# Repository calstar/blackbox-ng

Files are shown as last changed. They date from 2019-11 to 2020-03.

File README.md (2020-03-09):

View this project on [CADLAB.io](https://cadlab.io/project/2320). 

# blackbox-ng
This is the third major revision of STAR's black box project. Previous versions may be found on this git, and even older versions may be found on grabcad.

The major changes in this revision are the switch to kicad, the adjustment of the mounting holes pattern, and the switch to a more reliable linear regulator.

The project is seperated into a main logging board, and several spi daughter boards which can be chained together on an ffc cable and mounted about the vehicle.

## Daughter Boards

At present all daughter boards use jumpers to select the appropriate chipselect lines, but pin mappings are designed to allow us to chain an arbitrary number of devices on a single chain using 74 series shift registers. They also all share a common hole pattern and form factor.

### adxl372

This daughter board has a footprint for the adxl372, as well as a footprint for it's breakout board. The adxl372 is a relatively high bandwidth mems accelerometer that we plan on using to derive vibration data from.

### Debug Board (aka vronsky-daughter)

This board has a .1" header so that it can be used to access the signals of all the pins on its connector. It also has a footprint for a high speed barometric pressure sensor, in order to serve as a backup logging system for the pitot tube project.

### BMP388

This board is currently under development by Zitao and an attachment for STAR's next standard barometric pressure sensor. It is not yet production ready, but will likely be going out in the next board run.

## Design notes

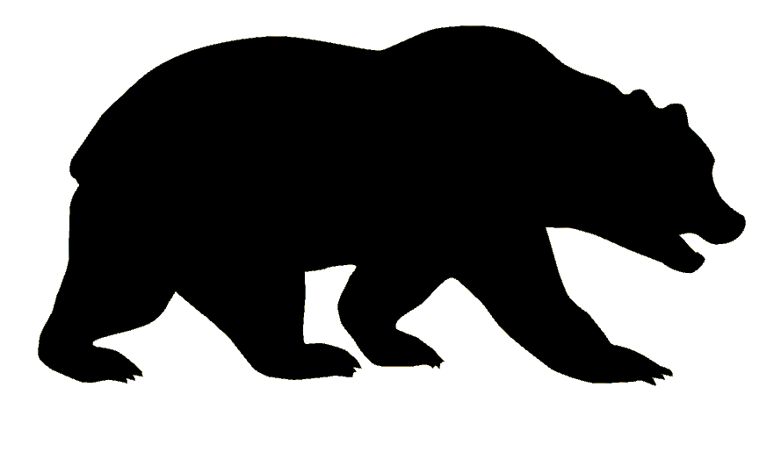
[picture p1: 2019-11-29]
art/bear.png

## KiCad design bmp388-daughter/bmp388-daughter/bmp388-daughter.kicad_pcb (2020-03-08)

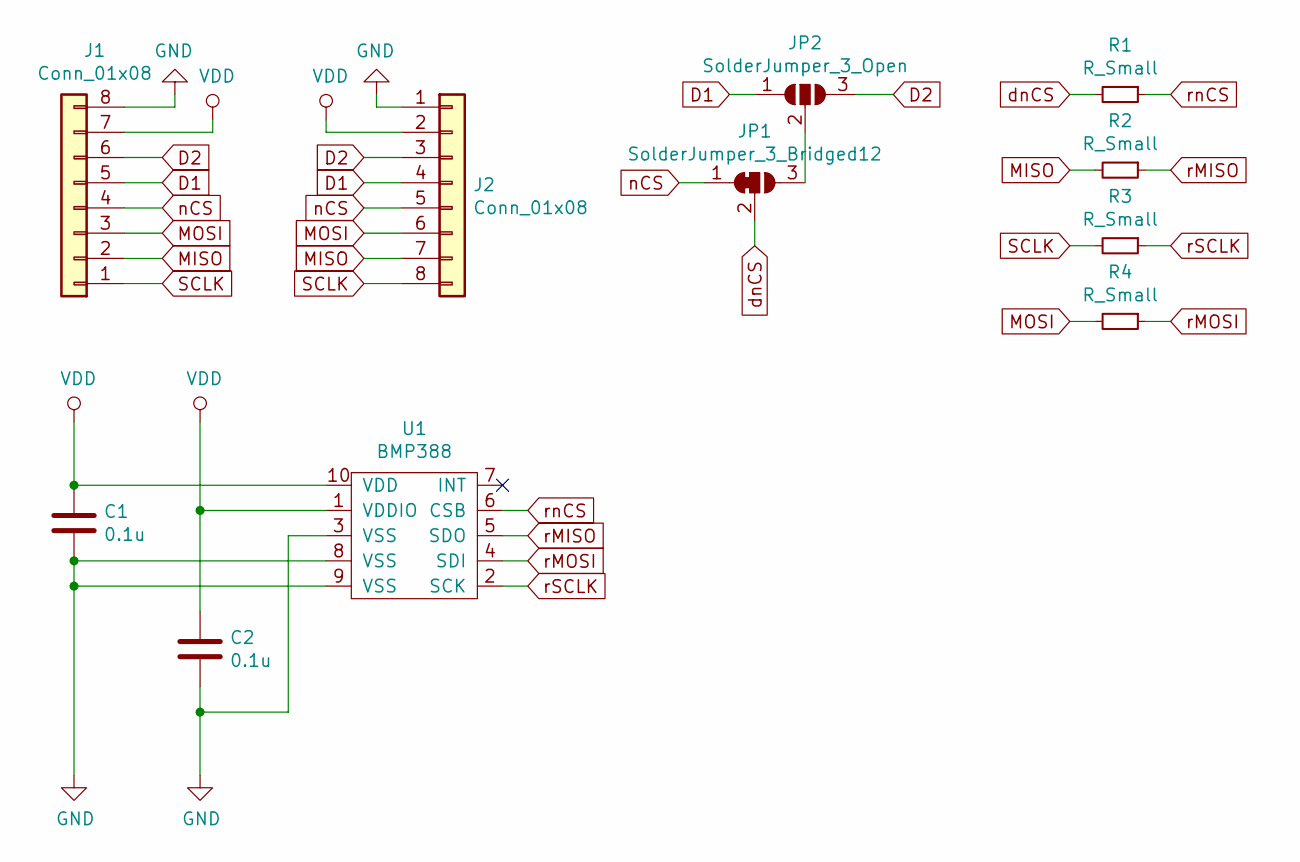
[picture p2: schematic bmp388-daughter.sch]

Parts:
C1, C2: 0.1u; C_0603_1608Metric_Pad1.05x0.95mm_HandSolder
J1, J2: Conn_01x08; 505110-0892
JP1: SolderJumper_3_Bridged12; SolderJumper-3_P1.3mm_Bridged2Bar12_Pad1.0x1.5mm
JP2: SolderJumper_3_Open; SolderJumper-3_P1.3mm_Open_Pad1.0x1.5mm
R1, R2, R3, R4: R_Small; R_0603_1608Metric_Pad1.05x0.95mm_HandSolder
U1: BMP388

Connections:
D1: J1.5, J2.4, JP2.1 (A)
D2: J1.6, J2.3, JP2.3 (B)
GND: C1.2, C2.2, J1.8, J2.1, U1.3 (VSS), U1.8 (VSS), U1.9 (VSS)
MISO: J1.2, J2.7, R2.2
MOSI: J1.3, J2.6, R4.2
unnamed: JP1.3 (B), JP2.2 (C)
SCLK: J1.1, J2.8, R3.2
VDD: C1.1, C2.1, J1.7, J2.2, U1.1 (VDDIO), U1.10 (VDD)
dnCS: JP1.2 (C), R1.2
nCS: J1.4, J2.5, JP1.1 (A)
rMISO: R2.1, U1.5 (SDO)
rMOSI: R4.1, U1.4 (SDI)
rSCLK: R3.1, U1.2 (SCK)
rnCS: R1.1, U1.6 (CSB)

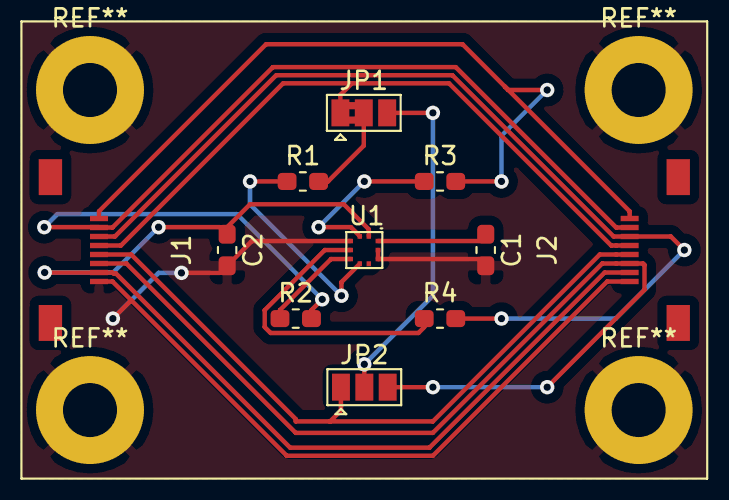
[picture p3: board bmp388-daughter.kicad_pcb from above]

Board: 2 copper layers, 11 parts (0 on the bottom side), 14 nets.

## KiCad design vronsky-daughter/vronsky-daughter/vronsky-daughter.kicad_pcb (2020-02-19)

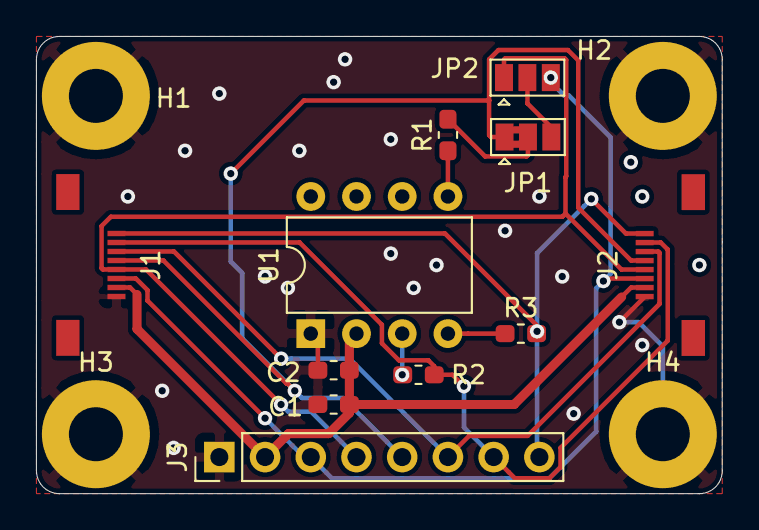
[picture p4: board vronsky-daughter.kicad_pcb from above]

Board: 2 copper layers, 38.1 x 25.4 mm, 15 parts (0 on the bottom side), 13 nets.

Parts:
C1: 1u; C_0603_1608Metric_Pad1.05x0.95mm_HandSolder
C2: 0.1u; C_0603_1608Metric_Pad1.05x0.95mm_HandSolder
H1, H2, H3, H4: MountingHole_3mm_Pad
J1, J2: Conn_01x08; 505110-0892
J3: Conn_01x08_Male; PinHeader_1x08_P2.54mm_Vertical
JP1: SolderJumper_3_Bridged12; SolderJumper-3_P1.3mm_Bridged2Bar12_Pad1.0x1.5mm
JP2: SolderJumper_3_Open; SolderJumper-3_P1.3mm_Open_Pad1.0x1.5mm
R1, R2, R3: R_Small; R_0603_1608Metric_Pad1.05x0.95mm_HandSolder
U1: HSCSPI; DIP-8_W7.62mm

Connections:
D1: J1.5, J2.4, J3.4, JP2.1
D2: J1.6, J2.3, J3.3, JP2.3
GND: C1.1, C2.1, H1.1, H2.1, H3.1, H4.1, J1.8, J2.1, J3.1, U1.1
MISO: J1.2, J2.7, J3.7, R2.2
MOSI: J1.3, J2.6, J3.6
unnamed: JP1.3, JP2.2
SCLK: J1.1, J2.8, J3.8, R3.2
VDD: C1.2, C2.2, J1.7, J2.2, J3.2, U1.2
dnCS: JP1.2, R1.2
nCS: J1.4, J2.5, J3.5, JP1.1
rMISO: R2.1, U1.3
rSCLK: R3.1, U1.4
rnCS: R1.1, U1.5

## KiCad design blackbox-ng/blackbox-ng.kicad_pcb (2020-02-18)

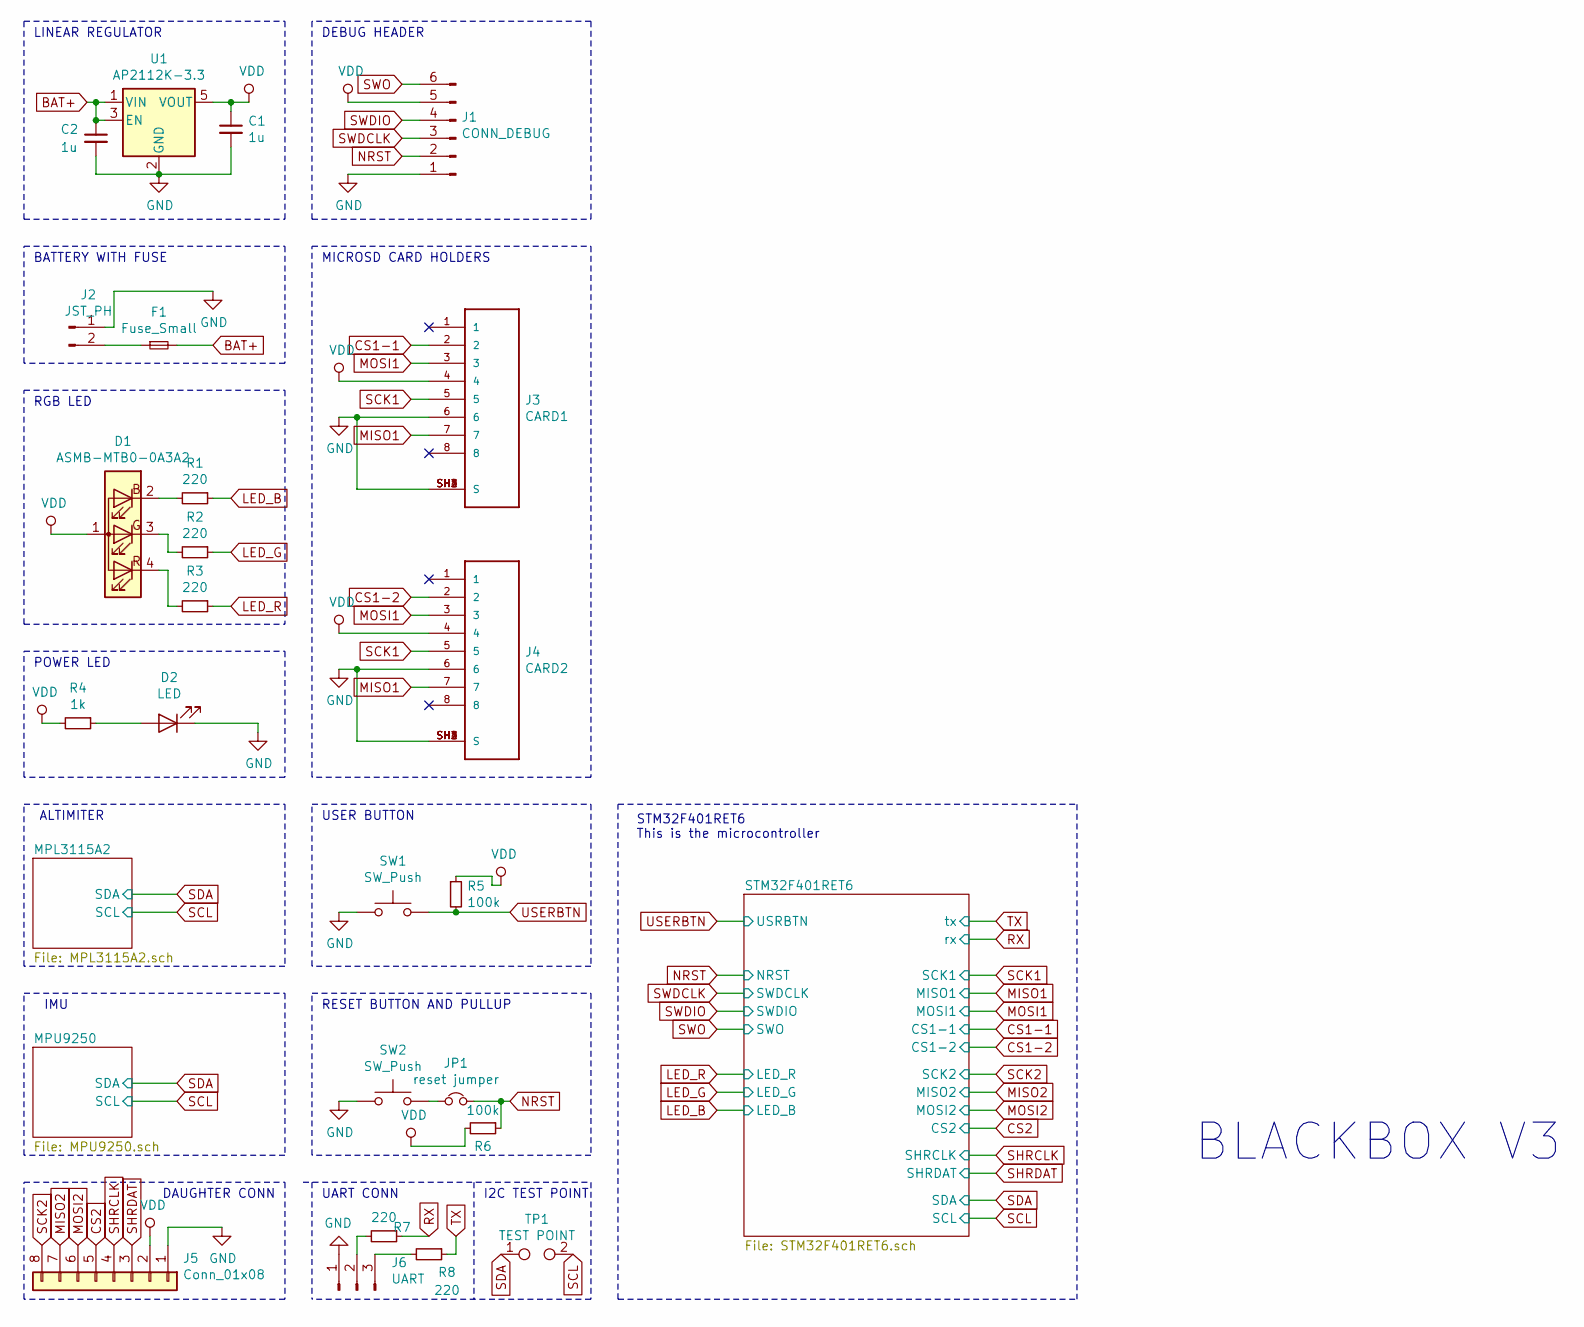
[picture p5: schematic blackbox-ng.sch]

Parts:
C1, C2: 1u; C_0603_1608Metric_Pad1.05x0.95mm_HandSolder
D1: ASMB-MTB0-0A3A2; LED_Avago_PLCC4_3.2x2.8mm_CW
D2: LED; LED_0603_1608Metric_Castellated
F1: Fuse_Small; Fuse_0603_1608Metric_Pad1.05x0.95mm_HandSolder
J1: CONN_DEBUG; PinHeader_1x06_P2.54mm_Vertical
J2: JST_PH; JST_PH_B2B-PH-K_1x02_P2.00mm_Vertical
J3: CARD1; MOLEX_500901-0801
J4: CARD2; MOLEX_500901-0801
J5: Conn_01x08; 505110-0892
J6: UART; PinHeader_1x03_P2.54mm_Vertical
JP1: reset jumper; SolderJumper-2_P1.3mm_Bridged2Bar_Pad1.0x1.5mm
R1, R2, R3, R7, R8: 220; R_0603_1608Metric_Pad1.05x0.95mm_HandSolder
R4: 1k; R_0603_1608Metric_Pad1.05x0.95mm_HandSolder
R5, R6: 100k; R_0603_1608Metric_Pad1.05x0.95mm_HandSolder
SW1, SW2: SW_Push; SW_SPST_B3S-1000
TP1: TEST POINT; TestPoint_2Pads_Pitch2.54mm_Drill0.8mm
U1: AP2112K-3.3; SOT-23-5

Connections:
BAT+: C2.1, F1.2, U1.1 (VIN), U1.3 (EN)
CS1-1: J3.2; also elsewhere on the board
CS1-2: J4.2; also elsewhere on the board
CS2: J5.5; also elsewhere on the board
GND: C1.2, C2.2, D2.1 (K), J1.1, J2.1, J3.6, J3.SH1 (S), J3.SH2 (S), J3.SH3 (S), J3.SH4 (S), J4.6, J4.SH1 (S), J4.SH2 (S), J4.SH3 (S), J4.SH4 (S), J5.1, J6.1, SW1.1, SW2.1, U1.2 (GND); also elsewhere on the board
LED_B: R1.1; also elsewhere on the board
LED_G: R2.1; also elsewhere on the board
LED_R: R3.1; also elsewhere on the board
MISO1: J3.7, J4.7; also elsewhere on the board
MISO2: J5.7; also elsewhere on the board
MOSI1: J3.3, J4.3; also elsewhere on the board
MOSI2: J5.6; also elsewhere on the board
NRST: J1.2, JP1.2, R6.1; also elsewhere on the board
unnamed: D1.2 (BK), R1.2
unnamed: D1.3 (GK), R2.2
unnamed: D1.4 (RK), R3.2
unnamed: D2.2 (A), R4.1
unnamed: F1.1, J2.2
unnamed: J6.2, R7.2
unnamed: J6.3, R8.2
unnamed: JP1.1, SW2.2
RX: R7.1; also elsewhere on the board
SCK1: J3.5, J4.5; also elsewhere on the board
SCK2: J5.8; also elsewhere on the board
SCL: TP1.2; also elsewhere on the board
SDA: TP1.1; also elsewhere on the board
SHRCLK: J5.4; also elsewhere on the board
SHRDAT: J5.3; also elsewhere on the board
SWDCLK: J1.3; also elsewhere on the board
SWDIO: J1.4; also elsewhere on the board
SWO: J1.6; also elsewhere on the board
TX: R8.1; also elsewhere on the board
USERBTN: R5.2, SW1.2; also elsewhere on the board
VDD: C1.1, D1.1 (A), J1.5, J3.4, J4.4, J5.2, R4.2, R5.1, R6.2, U1.5 (VOUT); also elsewhere on the board

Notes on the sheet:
LINEAR REGULATOR
BATTERY WITH FUSE
RGB LED
POWER LED
ALTIMITER
IMU
DEBUG HEADER
MICROSD CARD HOLDERS
USER BUTTON
RESET BUTTON AND PULLUP
DAUGHTER CONN
UART CONN
I2C TEST POINT
STM32F401RET6 This is the microcontroller
BLACKBOX V3

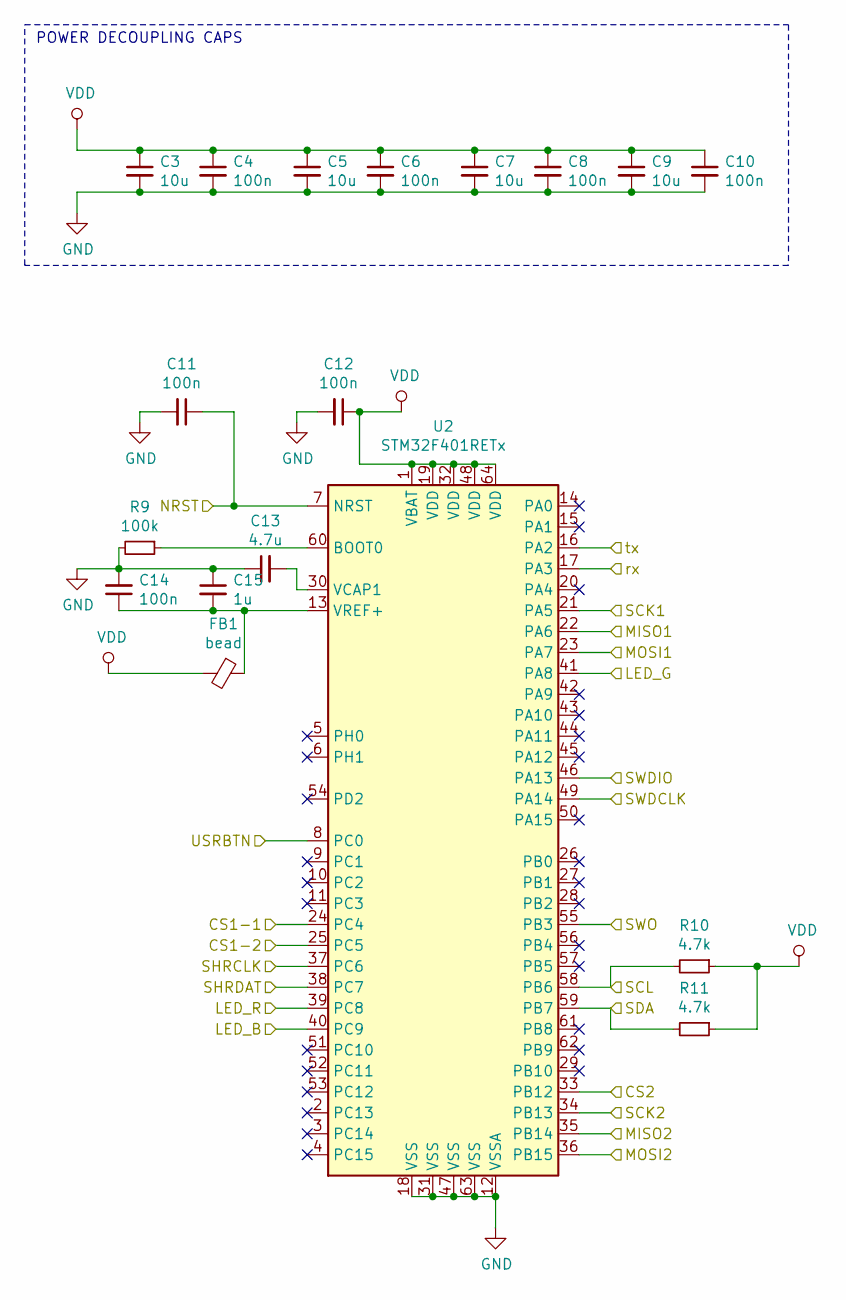
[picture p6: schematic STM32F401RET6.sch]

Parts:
C3, C5, C7, C9: 10u; C_0603_1608Metric_Pad1.05x0.95mm_HandSolder
C4, C6, C8, C10, C11, C12, C14: 100n; C_0603_1608Metric_Pad1.05x0.95mm_HandSolder
C13: 4.7u; C_0603_1608Metric_Pad1.05x0.95mm_HandSolder
C15: 1u; C_0603_1608Metric_Pad1.05x0.95mm_HandSolder
FB1: bead; L_0603_1608Metric_Pad1.05x0.95mm_HandSolder
R9: 100k; R_0603_1608Metric_Pad1.05x0.95mm_HandSolder
R10, R11: 4.7k; R_0603_1608Metric_Pad1.05x0.95mm_HandSolder
U2: STM32F401RETx; LQFP-64_10x10mm_P0.5mm

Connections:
CS1-1: U2.24 (PC4); also elsewhere on the board
CS1-2: U2.25 (PC5); also elsewhere on the board
CS2: U2.33 (PB12); also elsewhere on the board
GND: C3.2, C4.2, C5.2, C6.2, C7.2, C8.2, C9.2, C10.2, C11.2, C12.2, C13.1, C14.2, C15.1, R9.2, U2.12 (VSSA), U2.18 (VSS), U2.31 (VSS), U2.47 (VSS), U2.63 (VSS); also elsewhere on the board
LED_B: U2.40 (PC9); also elsewhere on the board
LED_G: U2.41 (PA8); also elsewhere on the board
LED_R: U2.39 (PC8); also elsewhere on the board
MISO1: U2.22 (PA6); also elsewhere on the board
MISO2: U2.35 (PB14); also elsewhere on the board
MOSI1: U2.23 (PA7); also elsewhere on the board
MOSI2: U2.36 (PB15); also elsewhere on the board
NRST: C11.1, U2.7 (NRST); also elsewhere on the board
unnamed: C13.2, U2.30 (VCAP1)
unnamed: C14.1, C15.2, FB1.1, U2.13 (VREF+)
unnamed: R9.1, U2.60 (BOOT0)
RX: U2.17 (PA3); also elsewhere on the board
SCK1: U2.21 (PA5); also elsewhere on the board
SCK2: U2.34 (PB13); also elsewhere on the board
SCL: R10.2, U2.58 (PB6); also elsewhere on the board
SDA: R11.2, U2.59 (PB7); also elsewhere on the board
SHRCLK: U2.37 (PC6); also elsewhere on the board
SHRDAT: U2.38 (PC7); also elsewhere on the board
SWDCLK: U2.49 (PA14); also elsewhere on the board
SWDIO: U2.46 (PA13); also elsewhere on the board
SWO: U2.55 (PB3); also elsewhere on the board
TX: U2.16 (PA2); also elsewhere on the board
USERBTN: U2.8 (PC0); also elsewhere on the board
VDD: C3.1, C4.1, C5.1, C6.1, C7.1, C8.1, C9.1, C10.1, C12.1, FB1.2, R10.1, R11.1, U2.1 (VBAT), U2.19 (VDD), U2.32 (VDD), U2.48 (VDD), U2.64 (VDD); also elsewhere on the board

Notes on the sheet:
POWER DECOUPLING CAPS

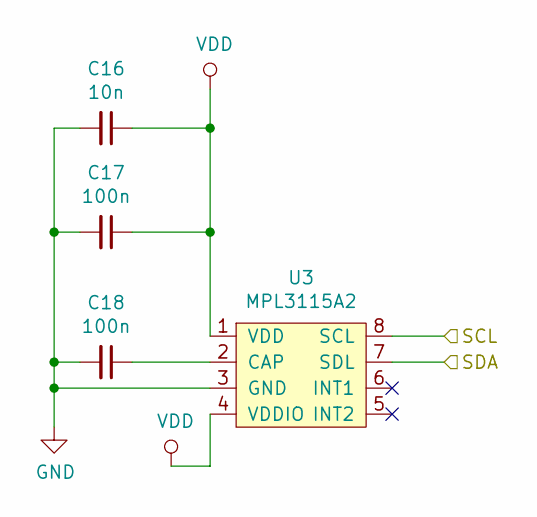
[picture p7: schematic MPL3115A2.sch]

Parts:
C16: 10n; C_0603_1608Metric_Pad1.05x0.95mm_HandSolder
C17, C18: 100n; C_0603_1608Metric_Pad1.05x0.95mm_HandSolder
U3: MPL3115A2; NXP_LGA-8_3x5mm_P1.25mm_H1.1mm

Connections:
GND: C16.2, C17.2, C18.2, U3.3 (GND); also elsewhere on the board
unnamed: C18.1, U3.2 (CAP)
SCL: U3.8 (SCL); also elsewhere on the board
SDA: U3.7 (SDL); also elsewhere on the board
VDD: C16.1, C17.1, U3.1 (VDD), U3.4 (VDDIO); also elsewhere on the board

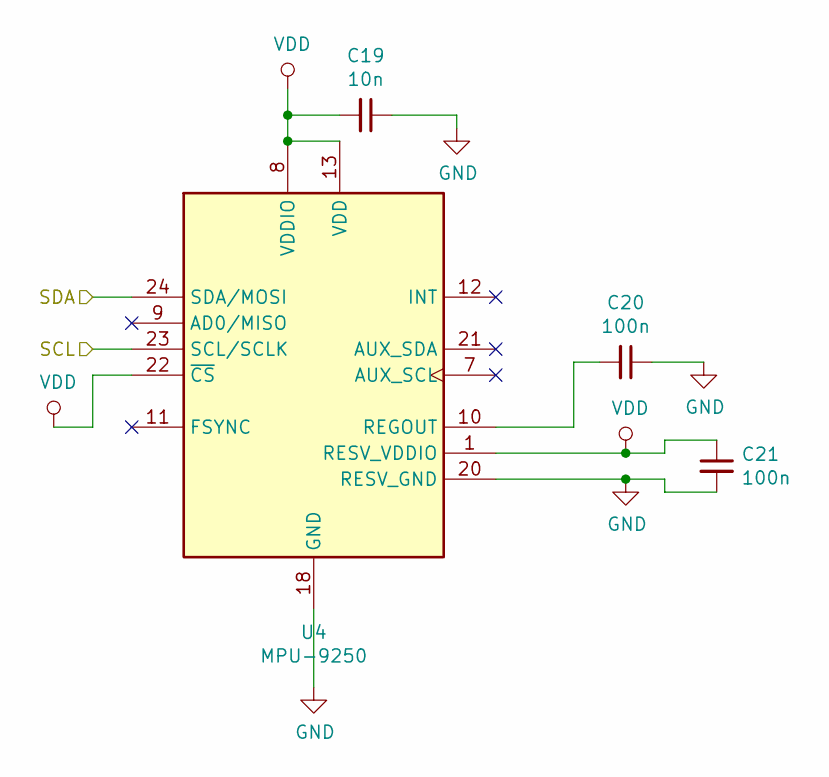
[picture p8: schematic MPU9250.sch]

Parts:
C19: 10n; C_0603_1608Metric_Pad1.05x0.95mm_HandSolder
C20, C21: 100n; C_0603_1608Metric_Pad1.05x0.95mm_HandSolder
U4: MPU-9250; InvenSense_QFN-24_3x3mm_P0.4mm

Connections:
GND: C19.1, C20.1, C21.2, U4.18 (GND), U4.20 (RESV_GND); also elsewhere on the board
unnamed: C20.2, U4.10 (REGOUT)
SCL: U4.23 (SCL/SCLK); also elsewhere on the board
SDA: U4.24 (SDA/MOSI); also elsewhere on the board
VDD: C19.2, C21.1, U4.1 (RESV_VDDIO), U4.8 (VDDIO), U4.13 (VDD), U4.22 (~CS); also elsewhere on the board

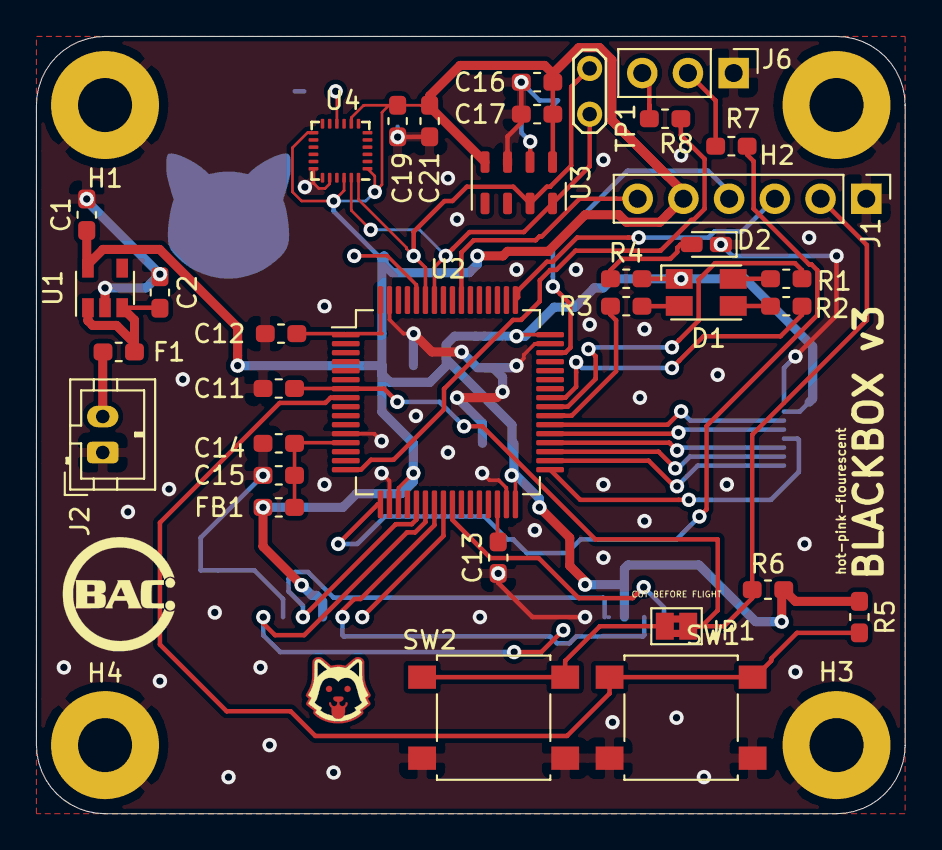
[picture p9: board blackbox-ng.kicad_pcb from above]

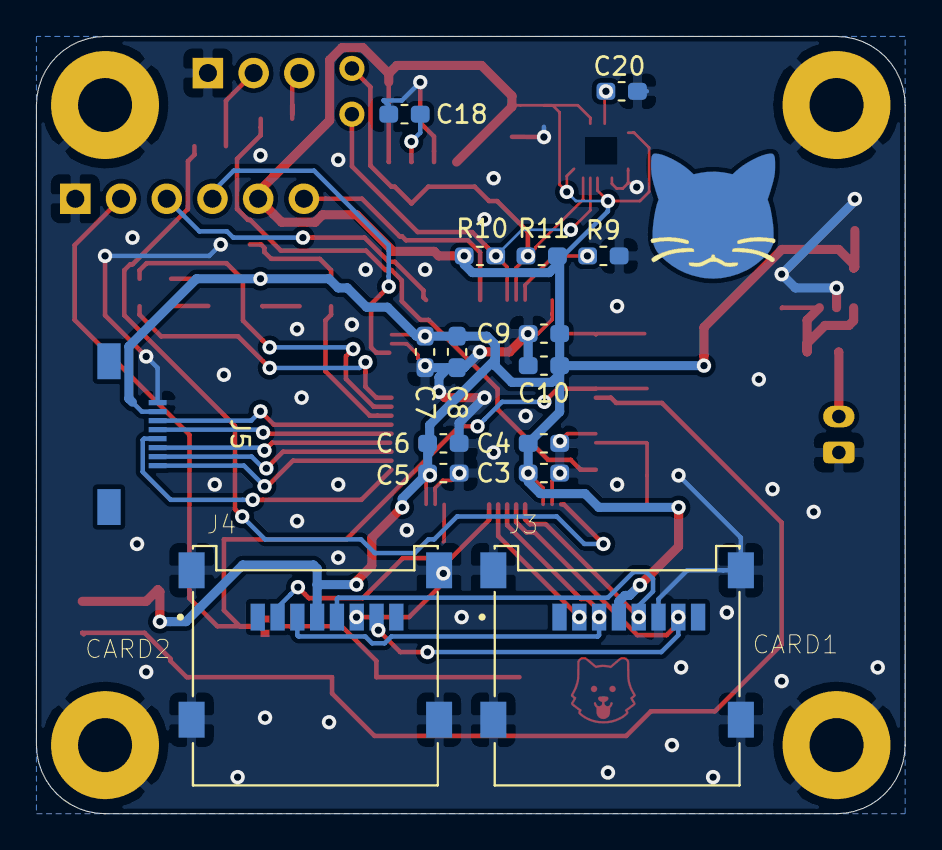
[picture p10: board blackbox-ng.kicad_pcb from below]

Board: 2 copper layers, 48.3 x 43.2 mm, 54 parts (16 on the bottom side), 39 nets.

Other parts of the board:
H1, H2, H3, H4: MountingHole_3mm_Pad

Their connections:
GND: H1.1, H2.1, H3.1, H4.1; also elsewhere on the board

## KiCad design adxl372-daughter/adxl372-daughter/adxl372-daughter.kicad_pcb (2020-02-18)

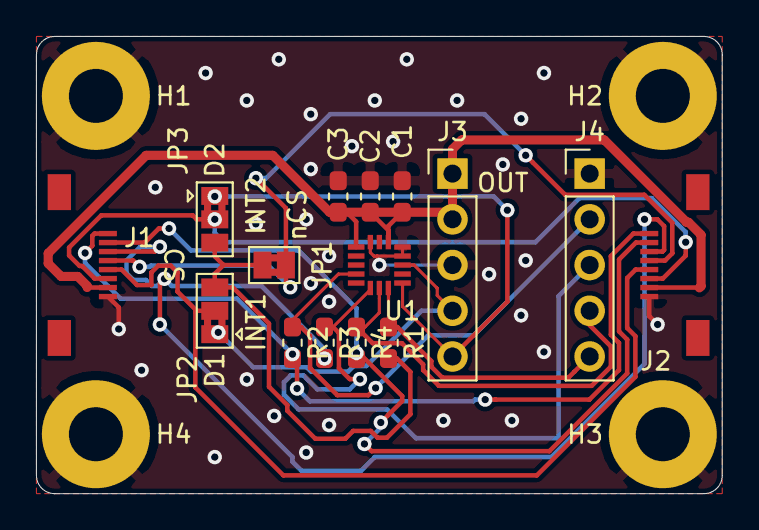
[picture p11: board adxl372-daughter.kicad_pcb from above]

Board: 2 copper layers, 38.1 x 25.4 mm, 19 parts (0 on the bottom side), 15 nets.

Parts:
C1: 1u; C_0603_1608Metric_Pad1.05x0.95mm_HandSolder
C2, C3: 0.1u; C_0603_1608Metric_Pad1.05x0.95mm_HandSolder
H1, H2, H3, H4: MountingHole_3mm_Pad
J1, J2: Conn_01x08; 505110-0892
J3, J4: Conn_01x05_Female; PinHeader_1x05_P2.54mm_Vertical
JP1: SolderJumper_2_Bridged; SolderJumper-2_P1.3mm_Bridged2Bar_Pad1.0x1.5mm
JP2, JP3: SolderJumper_3_Bridged12; SolderJumper-3_P1.3mm_Bridged2Bar12_Pad1.0x1.5mm
R1, R2, R3, R4: 0; R_0603_1608Metric_Pad1.05x0.95mm_HandSolder
U1: ADXL372

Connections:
D1: J1.5, J2.4, JP2.2
D2: J1.6, J2.3, JP3.2
GND: C1.1, C2.1, C3.1, H1.1, H2.1, H3.1, H4.1, J1.8, J2.1, J3.3, J4.1, U1.12, U1.13, U1.16
INT1: J3.4, JP2.1, U1.11
INT2: J3.5, JP3.1, U1.9
MISO: J1.2, J2.7, R4.2
MOSI: J1.3, J2.6, R3.2
SCLK: J1.1, J2.8, R2.2
VDD: C1.2, C2.2, C3.2, J1.7, J2.2, J3.1, J3.2, U1.1, U1.14
dnCS: JP1.2, JP2.3, JP3.3, R1.2
nCS: J1.4, J2.5, JP1.1
rMISO: J4.4, R4.1, U1.7
rMOSI: J4.3, R3.1, U1.6
rSCLK: J4.2, R2.1, U1.4
rnCS: J4.5, R1.1, U1.8

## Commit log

2019-11-27 start project and create stm sheet
    [STM32F401RET6.sch, blackbox-ng.kicad_pcb, blackbox-ng.sch]
2019-11-27 add linear regulator
    [blackbox-ng.sch]
2019-11-27 add battery
    [blackbox-ng.sch]
2019-11-27 add power led
    [blackbox-ng.sch]
2019-11-27 add mpl
    [MPL3115A2.sch, STM32F401RET6.sch, blackbox-ng.sch]
2019-11-27 add MPU9250 IMU
    [MPL3115A2.sch, MPU9250.sch, STM32F401RET6.sch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]
2019-11-27 add sdcard and buttons
    [blackbox-ng.sch]
2019-11-28 complete schematic
    [blackbox-ng.sch]
2019-11-28 assign footprints
    [MPL3115A2.sch, MPU9250.sch, STM32F401RET6.sch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]
2019-11-28 do initial layout
    [STM32F401RET6.sch, blackbox-ng.kicad_pcb, blackbox-ng.sch]
2019-11-28 add logos
    [blackbox-ng.kicad_pcb]
2019-11-28 add very important board functionality
    [blackbox-ng.kicad_pcb]
2019-11-29 something something golden bears
    [blackbox-ng.kicad_pcb]
2020-02-18 cleanup layout
    [blackbox-ng.kicad_pcb]
2020-02-18 add daughter part 2
    [adxl372-daughter.kicad_pcb, adxl372-daughter.sch]
2020-02-18 fleshed out daughter card
    [adxl372-daughter.kicad_pcb, adxl372-daughter.sch, blackbox-ng.kicad_pcb]
2020-02-18 made suggested edits
    [blackbox-ng.kicad_pcb]
2020-02-18 improved ground conectivity
    [adxl372-daughter.kicad_pcb]
2020-02-18 make pass drc
    [adxl372-daughter.kicad_pcb, blackbox-ng.kicad_pcb]
2020-02-19 add breakout
    [vronsky-daughter.kicad_pcb, vronsky-daughter.sch]
2020-03-08 BMP388 Breakout done
    [bmp388-daughter.kicad_pcb, bmp388-daughter.sch]
